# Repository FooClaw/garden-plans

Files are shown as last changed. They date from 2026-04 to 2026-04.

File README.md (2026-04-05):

# Garden Plans - Projets 3D pour le jardin

Modeles 3D parametriques (STL + plans techniques PDF) pour des meubles
de jardin a fabriquer soi-meme a partir de materiaux recycles.

## Projets

### Table basse en palettes recyclees

Repertoire : [`table_basse_palette/`](table_basse_palette/)

Table basse 100% bois de palette (1200 x 600 x 450 mm), inspiree du
projet [DIY Pallet Table](https://www.instructables.com/DIY-PALLET-TABLE-100-PALLET-WOOD/)
sur Instructables.

- Modele 3D (STL) + plan technique (PDF)
- Nomenclature detaillee avec guide de debit depuis 2 euro-palettes
- Guide de construction illustre pas a pas (12 pages)

### Chaise de jardin empilable en palettes recyclees

Repertoire : [`chaise_jardin_palette/`](chaise_jardin_palette/)

Chaise empilable adaptee a la table basse (assise 370 mm), inspiree du
projet [A Deck Chair Made From Pallet Wood Leftovers](https://www.instructables.com/A-Deck-Chair-Made-From-Pallet-Wood-Leftovers/)
sur Instructables.

- 1 palette = 1 chaise (20 pieces)
- Design empilable (pieds arriere retreci)
- Modele 3D (STL) + plan technique + guide 11 pages + nomenclature PDF

## Pre-requis

```bash
pip install numpy numpy-stl matplotlib
```

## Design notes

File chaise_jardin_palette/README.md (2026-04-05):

# Deck Chair de Jardin en Palettes Recyclees

Chaise de jardin type deck chair, 100% bois de palette.
Design minimaliste : assise tres basse, dossier tres incline, sans accoudoirs.
Panneaux lateraux style palette (planche + blocs + planche).

Fidellement inspire du projet [A Deck Chair Made From Pallet Wood Leftovers](https://www.instructables.com/A-Deck-Chair-Made-From-Pallet-Wood-Leftovers/)
par Well Done Tips sur Instructables. Adaptee pour accompagner la table basse palette (450 mm).

## Design

- Panneaux lateraux style palette : planche basse + 3 blocs + planche haute (122 mm)
- Assise tres basse (144 mm) - position transat, genoux au-dessus des hanches
- Dossier incline a ~125 degres - position tres detendue
- Pas d'accoudoirs - design epure et minimaliste
- Lattes pleine largeur (95 mm) avec ecarts de 15 mm
- Assise courte (4 lattes) couvrant toute la largeur (600 mm)
- Longerons depassant de 350 mm a l'arriere pour la stabilite
- Supports dossier continus du sol au sommet, inclines a 35 degres

## Dimensions

| Element | Dimensions |
|---|---|
| Chaise (L x P x H) | 600 x 775 x 677 mm |
| Hauteur assise | 144 mm |
| Angle dossier | ~125 degres |
| Panneaux lateraux | 775 x 95 x 122 mm |
| Assise | 4 lattes de 600 x 95 x 22 mm |
| Dossier | 5 lattes de 410 x 95 x 22 mm |
| Supports dossier | 826 x 70 x 44 mm |
| Blocs lateraux | 44 x 44 x 78 mm |
| Pieces totales | 22 (7 references) |

## Fichiers

| Fichier | Description |
|---|---|
| `generate_table.py` | Generateur STL + PDF technique |
| `generate_guide.py` | Generateur guide construction PDF |
| `generate_nomenclature.py` | Generateur nomenclature PDF |
| `chaise_jardin_palette.stl` | Maillage 3D |
| `chaise_jardin_palette_plan.pdf` | Plan technique |
| `guide_construction.pdf` | Guide illustre |
| `nomenclature.pdf` | Nomenclature PDF |
| `NOMENCLATURE.md` | Nomenclature source |

## Usage

```bash
pip install numpy numpy-stl matplotlib
python3 generate_table.py
python3 generate_guide.py
python3 generate_nomenclature.py
```

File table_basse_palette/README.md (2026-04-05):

# Table Basse en Palettes Recyclees

Modele 3D d'une table basse 100% bois de palette, inspire du projet
[DIY Pallet Table](https://www.instructables.com/DIY-PALLET-TABLE-100-PALLET-WOOD/)
sur Instructables.

## Design

- Plateau 6 lattes de palette alignees
- Etagere inferieure pour le rangement
- 4 pieds en blocs de palette
- Entretoises laterales pour la rigidite
- Materiau : euro-palette recyclee (lattes 22 mm)

## Dimensions

| Element | Dimensions |
|---|---|
| Table (L x l x H) | 1200 x 600 x 450 mm |
| Lattes plateau | 95 x 22 mm (x6) |
| Pieds | 95 x 95 x 406 mm |
| Etagere | a 100 mm du sol |
| Entretoises | 70 x 22 mm |

## Fichiers

| Fichier | Description |
|---|---|
| `generate_table.py` | Script Python (numpy-stl + matplotlib) |
| `table_basse_palette.stl` | Maillage 3D pour visualisation / impression |
| `table_basse_palette_plan.pdf` | Plan technique avec vues de face, dessus et cote |

## Usage

```bash
python3 generate_table.py
```

Genere le STL et le PDF. Necessite `numpy`, `numpy-stl` et `matplotlib`.

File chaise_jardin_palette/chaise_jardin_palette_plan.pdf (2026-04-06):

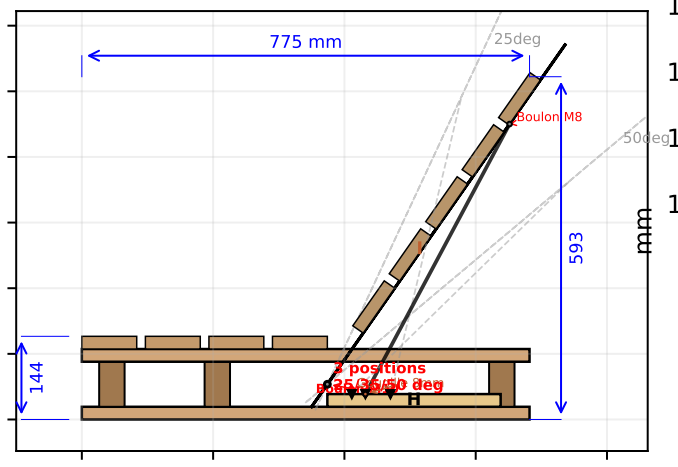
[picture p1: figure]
25deg; Boulon M8; 50deg; Boulon M10; Goupille 8mm; 3 positions 25/35/50 deg

0 | 50 | 100 | 150 | 200
| | mm

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
# Vue de cote

0 | 50 | 100 | 150 | 200
| | mm

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
600 mm

593

# Vue de face

0 | 20 | 40 | 60 | 80
| | mm

0

20

40

60

80

mm

600 mm

775 mm

# Vue de dessus

Objet : Deck Chair de Jardin en Palettes Recyclees
Dimensions : 600 x 775 x 593 mm (L x P x H) | | | Assise : 144 mm
Assise : 4 lattes | | | Dossier : 5 lattes, inclinable 3 positions (25/35/50 deg)
Mecanisme : 2 boulons M10 (pivot) + 2 boulons M8 (articulation) + goupille 8mm Panneaux lateraux style palette (planche + blocs 78 mm + planche)
Sans accoudoirs | | | Longerons depassent de 350 mm a l'arriere
Materiau : 1 euro-palette | | | 26 pieces | | | Echelle 1:1 (mm)
Inspire de : instructables.com/A-Deck-Chair-Made-From-Pallet-Wood-Leftovers

# Plan Technique - Deck Chair en Palettes Recyclees

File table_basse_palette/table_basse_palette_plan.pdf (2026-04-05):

0 200 400 600 800 1000 1200 mm

0

200

400

mm

1200 mm

450 mm

100

# Vue de face

0 200 400 600 800 1000 1200 mm

0

200

400

600

mm

1200 mm

600 mm

# Vue de dessus

0 100 200 300 400 500 600
mm

0

100

200

300

400

mm

600 mm

450 mm

# Vue de cote

Objet : Table Basse en Palettes Recyclees (100% bois de palette) Dimensions : 1200 x 600 x 450 mm (L x l x H)
Plateau : 6 lattes de 95 x 22 mm | | | Pieds : 95 x 95 x 406 mm
Etagere inferieure a 100 mm du sol | | | Entretoises : 70 x 22 mm
Materiau : Euro-palette recyclee (lattes 22 mm) | | | Echelle : 1:1 (mm)
Inspire de : instructables.com/DIY-PALLET-TABLE-100-PALLET-WOOD

# Plan Technique - Table Basse en Palettes Recyclees

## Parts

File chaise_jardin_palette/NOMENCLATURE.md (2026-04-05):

# Nomenclature - Deck Chair de Jardin en Palettes Recyclees

## Matiere premiere : Euro-palette

Il faut **1 euro-palette standard** (1200 x 800 mm) pour realiser 1 chaise.
Choisir une palette marquee **HT** (traitement thermique, sans produit chimique).
**Important** : conserver les blocs de palette (78 mm de haut) pour les panneaux lateraux.
22 pieces au total (7 references A-G).

---

## Recapitulatif de debit

| Ref | Piece | Qte | Dimensions (mm) | Origine palette |
|-----|---|-----|---|---|
| A | Latte assise | 4 | 600 x 95 x 22 | Lattes pleine largeur |
| B | Latte dossier | 5 | 410 x 95 x 22 | Lattes pleine largeur |
| C | Planche lat. basse | 2 | 775 x 95 x 22 | Lattes pleine largeur |
| D | Planche lat. haute | 2 | 775 x 95 x 22 | Lattes pleine largeur |
| E | Bloc lateral | 6 | 44 x 44 x 78 | Blocs de palette |
| F | Support dossier | 2 | 826 x 70 x 44 | 2 lattes collees |
| G | Traverse avant | 1 | 410 x 44 x 22 | Latte recoupee |
| | **Total pieces** | **22** | | **1 palette** |

---

## Structure des panneaux lateraux

Chaque panneau lateral est construit comme une mini-palette :

```
[=== Planche haute D (775 x 95 x 22) ===]
 [E]            [E]            [E]
[=== Planche basse C (775 x 95 x 22) ===]
```

Les blocs (E) sont espaces : avant, milieu et arriere du panneau.
Hauteur du panneau : 22 + 78 + 22 = **122 mm**.
Hauteur d'assise (avec latte) : 122 + 22 = **144 mm**.

---

## Instructions de debit

### Ref. A - Lattes d'assise (x4)
- **600 x 95 x 22 mm** - Lattes pleine largeur, recoupees a 600 mm
- Couvrent toute la largeur de la chaise, depassent des panneaux lateraux

### Ref. B - Lattes de dossier (x5)
- **410 x 95 x 22 mm** - Lattes pleine largeur, recoupees a 410 mm
- S'inserent entre les deux panneaux lateraux

### Ref. C/D - Planches laterales (2 + 2)
- **775 x 95 x 22 mm** - Lattes pleine largeur, recoupees a 775 mm
- Forment le bas (C) et le haut (D) des panneaux lateraux
- Depassent de 350 mm a l'arriere de l'assise

### Ref. E - Blocs lateraux (x6)
- **44 x 44 x 78 mm** - Blocs recuperes de la palette
- 3 par panneau (avant, milieu, arriere)
- Hauteur standard des blocs de palette euro

### Ref. F - Supports dossier (x2)
- **826 x 70 x 44 mm** - 2 lattes collees face a face
- Piece continue du sol au sommet du dossier, inclinee a ~35 deg de la verticale
- Boulonnee a travers le panneau lateral (2 boulons M8 par cote)
- La base repose au sol ~100 mm en avant de l'arriere de l'assise

### Ref. G - Traverse avant (x1)
- **410 x 44 x 22 mm** - Latte recoupee et refendue
- Relie les panneaux sous l'assise
- **410 x 44 x 22 mm** - Latte recoupee et refendue
- Relie les panneaux sous l'assise

---

## Outillage necessaire

| Outil | Usage |
|---|---|
| Pied-de-biche / levier | Demontage lattes et blocs |
| Arrache-clou / tenaille | Retrait des clous |
| Scie circulaire | Decoupe a longueur |
| Scie a onglet | Decoupe precision |
| Ponceuse orbitale | Poncage (grains 80, 120, 180) |
| Visseuse + vis 4x50 mm | Assemblage |
| Serre-joints (x4) | Collage supports dossier |
| Colle a bois D3 | Collage pieces doublees |
| Fausse equerre | Angle dossier (~125 deg) |

---

## Ordre d'assemblage

1. **Demontage** : Demonter la palette, conserver lattes ET blocs
2. **Debit** : Decouper toutes les pieces
3. **Poncage** : Poncer toutes les pieces
4. **Panneaux lateraux** : Planche basse + 3 blocs + planche haute (x2)
5. **Traverse** : Visser traverse avant G entre les panneaux
6. **Assise** : Visser 4 lattes A (espacement 15 mm)
7. **Supports dossier** : Boulonner supports F a travers les panneaux (angle ~35 deg)
8. **Dossier** : Visser 5 lattes B sur les supports
9. **Finition** : Huile de lin, vernis ou lasure

---

## Design

Fidellement inspire du projet Instructables
[A Deck Chair Made From Pallet Wood Leftovers](https://www.instructables.com/A-Deck-Chair-Made-From-Pallet-Wood-Leftovers/)
par Well Done Tips.

- Assise tres basse (144 mm) - position transat
- Dossier incline a ~125 deg
- Panneaux lateraux style palette (planche + blocs + planche)
- Lattes pleine largeur (95 mm) avec grands ecarts (15 mm)
- Longerons depassant de 350 mm a l'arriere
- Sans accoudoirs
- 1 palette suffit

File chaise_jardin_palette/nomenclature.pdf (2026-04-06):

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

# Quincaillerie (mecanisme)

Element | Qte | Usage
Boulon M10 x 120 + ecrou + 4 rondelles | 2 | Pivot dossier
Boulon M8 x 60 + ecrou papillon + 2 rondelles | 2 | Articulation barre stab.
Goupille fendue acier 8 mm x 50 mm | 2 | Verrouillage position
Vis a bois 4x50 mm | 50 | Assemblage general
Vis a bois 4x30 mm | 10 | Fixation rails

Tous les boulons sont en acier zingue (exterieur).

Les ecrous papillon permettent un reglage a la main.

# Ordre d'assemblage

Demontage

Demonter la palette, conserver lattes ET blocs

Debit

Decouper toutes les pieces aux bonnes dimensions

Poncage

Poncer toutes les pieces (grains 80, 120, 180)

Panneaux lat.

Planche basse + 3 blocs + planche haute (x2)

Traverses

Visser traverse avant G entre les panneaux

Assise

Visser 4 lattes A (espacement 15 mm)

Rails

Percer 3 trous de 10 mm dans H, fixer entre les planches

Supports

Coller F, monter sur pivot M10 au sommet du panneau

Barres stab.

Fixer barres I au support, pied sur rail + goupille

Dossier

Visser 5 lattes B sur supports

Verification

Tester les 3 positions, controler stabilite

Finition

Huile de lin, vernis ou lasure

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
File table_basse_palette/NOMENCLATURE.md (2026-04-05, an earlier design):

# Nomenclature - Table Basse en Palettes Recyclees

## Matiere premiere : Euro-palettes

Il faut **2 euro-palettes standard** (1200 x 800 mm) pour realiser cette table.
Choisir des palettes marquees **HT** (traitement thermique, sans produit chimique).
Eviter les palettes marquees **MB** (bromure de methyle, toxique).

```
Euro-palette standard (EPAL/EUR)
┌─────────────────────────────────────┐
│  1200 mm                            │
│ ┌──┐ ┌──┐ ┌──┐ ┌──┐ ┌──┐ ┌──┐ ┌──┐│
│ │  │ │  │ │  │ │  │ │  │ │  │ │  ││ 800 mm
│ └──┘ └──┘ └──┘ └──┘ └──┘ └──┘ └──┘│
│  7 lattes dessus (largeurs variables)│
│  9 blocs (plots)                     │
│  3 traverses + 3 lattes dessous      │
└─────────────────────────────────────┘
Epaisseur lattes : 22 mm
Largeur lattes : 95-145 mm (variable)
Hauteur totale : 144 mm
```

---

## Nomenclature des pieces

### Ref. A - Lattes du plateau (x6)

| Propriete | Valeur |
|---|---|
| Dimensions finies | 1200 x 95 x 22 mm |
| Origine sur palette | Lattes du dessus |
| Quantite necessaire | 6 |
| Palettes consommees | 2 (3 lattes par palette) |

**Debit :**
1. Retirer les lattes du dessus de la palette au pied-de-biche
2. Arracher les clous restants avec un arrache-clou ou une tenaille
3. Poncer les deux faces (grain 80, puis 120, puis 180)
4. Recouper a 1200 mm de long si necessaire
5. Selectionner les lattes de 95 mm de large (largeur standard)

> **Astuce :** Les lattes les plus larges (145 mm) peuvent etre refendues
> a la scie circulaire pour obtenir des lattes de 95 mm + des chutes
> utilisables pour les entretoises.

---

### Ref. B - Pieds (x4)

| Propriete | Valeur |
|---|---|
| Dimensions finies | 95 x 95 x 406 mm |
| Origine sur palette | Blocs (plots) empiles et colles |
| Quantite necessaire | 4 |
| Blocs par pied | 3 blocs empiles (3 x 144 mm ~ 432 mm, recoupe a 406 mm) |
| Blocs totaux | 12 (soit 2 palettes a 9 blocs = 18 disponibles) |

**Debit :**
1. Demonter la palette : retirer toutes les lattes dessus et dessous
2. Recuperer les 9 blocs (plots) par palette, ils restent solidaires des traverses
3. Scier les traverses au ras des blocs
4. Poncer les blocs (grain 80, puis 120)
5. Empiler 3 blocs et les coller a la colle a bois (serrer avec des serre-joints, 24h)
6. Une fois sec, recouper l'ensemble a 406 mm de hauteur a la scie a onglet
7. Poncer les faces de collage (grain 120)

> **Astuce :** Les blocs centraux de la palette font generalement
> 145 x 95 mm, et les blocs d'extremite 95 x 95 mm. Privilegier
> les blocs d'extremite pour des pieds carres reguliers.

---

### Ref. C - Lattes de l'etagere (x4)

| Propriete | Valeur |
|---|---|
| Dimensions finies | 1100 x 95 x 22 mm |
| Origine sur palette | Lattes du dessus ou du dessous |
| Quantite necessaire | 4 |
| Palettes consommees | Recuperation sur les memes palettes |

**Debit :**
1. Meme processus que les lattes du plateau (Ref. A)
2. Recouper a 1100 mm (= 1200 - 2 x 50 mm de retrait)
3. Poncer les deux faces

> **Note :** Les lattes du dessous de palette sont plus etroites
> (souvent 95 mm) et conviennent parfaitement pour l'etagere.

---

### Ref. D - Traverses du plateau (x3)

| Propriete | Valeur |
|---|---|
| Dimensions finies | 600 x 22 x 22 mm |
| Origine sur palette | Traverses ou lattes refendues |
| Quantite necessaire | 3 (2 laterales + 1 centrale) |
| Palettes consommees | Chutes des lattes |

**Debit :**
1. Recuperer les traverses de la palette (planches perpendiculaires aux lattes)
2. Les recouper a 600 mm de long (= largeur de la table)
3. Refendre en largeur a 22 mm si necessaire (epaisseur = largeur pour un profile carre)
4. Poncer (grain 120)

---

### Ref. E - Entretoises laterales (x2)

| Propriete | Valeur |
|---|---|
| Dimensions finies | 1010 x 22 x 70 mm |
| Longueur | 1200 - 2 x 95 = 1010 mm |
| Origine sur palette | Traverses ou lattes refendues a 70 mm |
| Quantite necessaire | 2 (avant + arriere) |

**Debit :**
1. Utiliser des traverses de palette ou des lattes larges
2. Refendre a 70 mm de largeur a la scie circulaire
3. Recouper a 1010 mm de long
4. Poncer (grain 120)

---

### Ref. F - Traverses de l'etagere (x2)

| Propriete | Valeur |
|---|---|
| Dimensions finies | 600 x 22 x 22 mm |
| Origine sur palette | Meme source que Ref. D |
| Quantite necessaire | 2 |

**Debit :** Identique a la Ref. D.

---

## Recapitulatif de debit

| Ref | Piece | Qte | Dimensions (mm) | Origine palette |
|-----|---|-----|---|---|
| A | Latte plateau | 6 | 1200 x 95 x 22 | Lattes dessus |
| B | Pied | 4 | 95 x 95 x 406 | 3 blocs colles |
| C | Latte etagere | 4 | 1100 x 95 x 22 | Lattes dessus/dessous |
| D | Traverse plateau | 3 | 600 x 22 x 22 | Traverses/chutes |
| E | Entretoise laterale | 2 | 1010 x 70 x 22 | Traverses/lattes |
| F | Traverse etagere | 2 | 600 x 22 x 22 | Traverses/chutes |
| | **Total pieces** | **21** | | **2 palettes** |

---

## Outillage necessaire

| Outil | Usage |
|---|---|
| Pied-de-biche / levier | Demontage des lattes |
| Arrache-clou / tenaille | Retrait des clous |
| Scie circulaire ou scie a onglet | Decoupe a longueur et refente |
| Ponceuse orbitale | Poncage (grains 80, 120, 180) |
| Serre-joints (x4 min.) | Collage des blocs pour les pieds |
| Visseuse + vis a bois (4x50 mm) | Assemblage |
| Colle a bois D3 (exterieur) | Collage des blocs pieds |
| Equerre de menuisier | Verification des angles droits |

---

## Ordre d'assemblage

1. **Demontage** : Demonter les 2 palettes, trier les pieces
2. **Debit** : Decouper toutes les pieces aux dimensions finales
3. **Poncage** : Poncer toutes les pieces avant assemblage
4. **Pieds** : Coller les blocs par 3, laisser secher 24h, recouper a 406 mm
5. **Cadre bas** : Visser les traverses etagere (F) entre les pieds
6. **Entretoises** : Visser les entretoises laterales (E) entre les pieds
7. **Etagere** : Poser et visser les lattes etagere (C) sur les traverses (F)
8. **Traverses plateau** : Visser les traverses (D) sur le haut des pieds
9. **Plateau** : Poser et visser les lattes (A) sur les traverses (D)
10. **Finition** : Huile de lin, vernis, ou lasure selon usage (interieur/exterieur)

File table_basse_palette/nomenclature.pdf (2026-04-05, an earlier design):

# Nomenclature

### Table Basse en Palettes Recyclees

# Liste de debit et instructions d'assemblage

Materiau : | 2 euro-palettes standard (1200 x 800 mm)
Dimensions table : | 1200 x 600 x 450 mm (L x l x H)
Nombre de pieces : | 21 pieces (6 references)
Outillage : | 9 outils necessaires
Etapes : | 10 etapes d'assemblage

Choisir des palettes marquees HT (traitement thermique)

Eviter les palettes marquees MB (bromure de methyle, toxique)

Euro-palette 1200 x 800 mm

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

# Instructions de debit (1/2)

Ref. A - Latte plateau | x6
Dimensions : 1200 x 95 x 22 mm | Origine : Lattes du dessus

Retirer les lattes du dessus au pied-de-biche

Arracher les clous restants a la tenaille

Poncer les deux faces (grain 80, puis 120, puis 180)

Recouper a 1200 mm de long si necessaire

Selectionner les lattes de 95 mm de large
Ref. B - Pied (3 blocs colles) | x4
Dimensions : 95 x 95 x 406 mm | Origine : Blocs empiles

Demonter la palette : retirer toutes les lattes

Recuperer les 9 blocs (plots) par palette

Scier les traverses au ras des blocs

Poncer les blocs (grain 80, puis 120)

Empiler 3 blocs, coller a la colle D3 (serre-joints, 24h)

Recouper l'ensemble a 406 mm a la scie a onglet
Ref. C - Latte etagere | x4
Dimensions : 1100 x 95 x 22 mm | Origine : Lattes dessus/dessous

Meme processus que les lattes du plateau (Ref. A)

Recouper a 1100 mm (= 1200 - 2 x 50 mm de retrait)

Les lattes du dessous conviennent parfaitement

# Instructions de debit (2/2)

Ref. D - Traverse plateau | x3
Dimensions : 600 x 22 x 22 mm | Origine : Traverses / chutes

Recuperer les traverses de la palette

Recouper a 600 mm de long (= largeur de la table)

Refendre en largeur a 22 mm si necessaire
Ref. E - Entretoise laterale | x2
Dimensions : 1010 x 70 x 22 mm | Origine : Traverses refendues

Utiliser des traverses ou des lattes larges

Refendre a 70 mm de largeur a la scie circulaire

Recouper a 1010 mm de long
Ref. F - Traverse etagere | x2
Dimensions : 600 x 22 x 22 mm | Origine : Traverses / chutes

Identique a la Ref. D

Recouper a 600 mm de long

# Outillage necessaire

Outil | Usage
Pied-de-biche / levier | Demontage des lattes
Arrache-clou / tenaille | Retrait des clous
Scie circulaire ou scie a onglet | Decoupe a longueur et refente
Ponceuse orbitale | Poncage (grains 80, 120, 180)
Visseuse + vis a bois (4x50 mm) | Assemblage
Serre-joints (x4 min.) | Collage des blocs pour les pieds
Colle a bois D3 (exterieur) | Collage des blocs pieds
Equerre de menuisier | Verification des angles droits
Metre ruban + crayon | Tracage et mesures

# Ordre d'assemblage

Demontage

Demonter les 2 palettes, trier les pieces

Debit

Decouper toutes les pieces aux dimensions finales

Poncage

Poncer toutes les pieces avant assemblage

Pieds

Coller les blocs par 3, laisser secher 24h, recouper a 406 mm

Cadre bas

Visser les traverses etagere (F) entre les pieds

Entretoises

Visser les entretoises laterales (E) entre les pieds

Etagere

Poser et visser les lattes etagere (C) sur les traverses (F)

Traverses plateau

Visser les traverses (D) sur le haut des pieds

Plateau

Poser et visser les lattes (A) sur les traverses (D)

Finition

Huile de lin, vernis, ou lasure selon usage

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
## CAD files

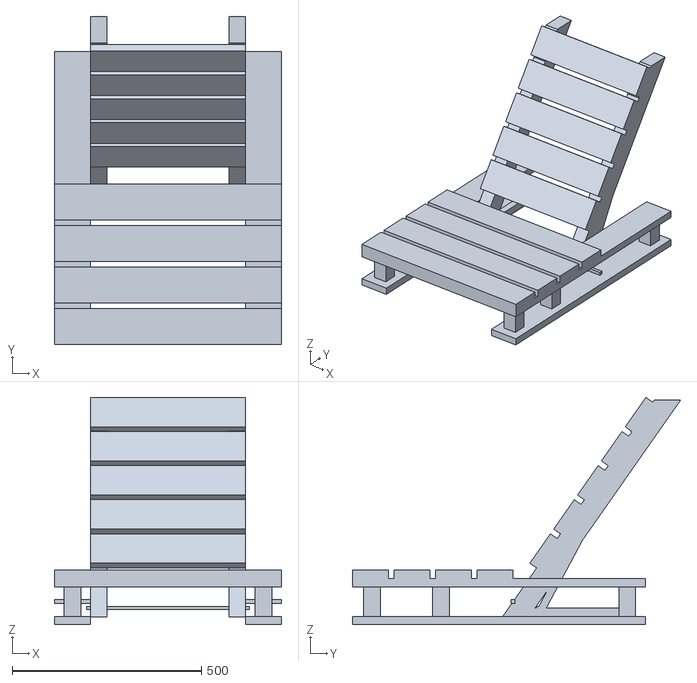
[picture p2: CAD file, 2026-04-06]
chaise_jardin_palette/chaise_jardin_palette.stl
600.0 x 867.8 x 600.5

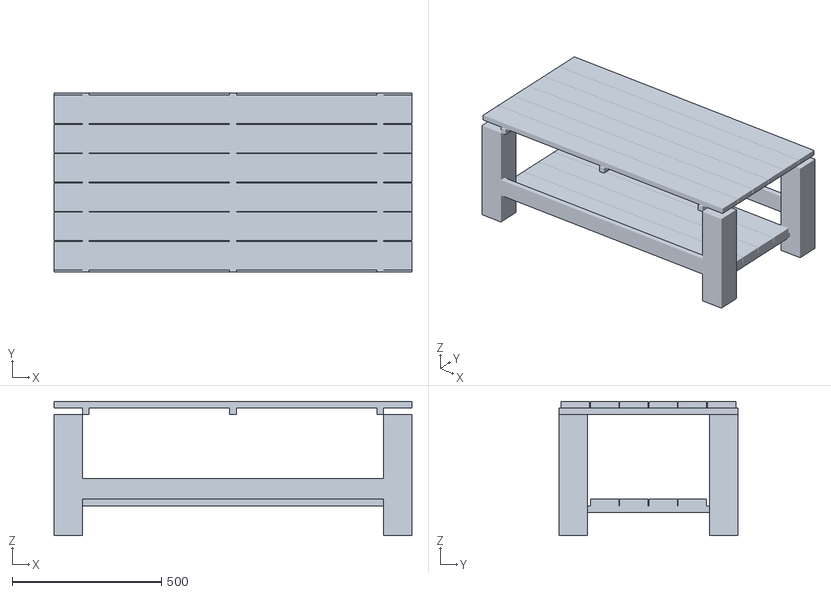
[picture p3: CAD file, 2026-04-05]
table_basse_palette/table_basse_palette.stl
1200.0 x 600.0 x 450.0

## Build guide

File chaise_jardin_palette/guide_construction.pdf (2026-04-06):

# Guide de Construction

## Deck Chair de Jardin en Palettes Recyclees

# Dossier inclinable 3 positions - mecanisme cremaillere

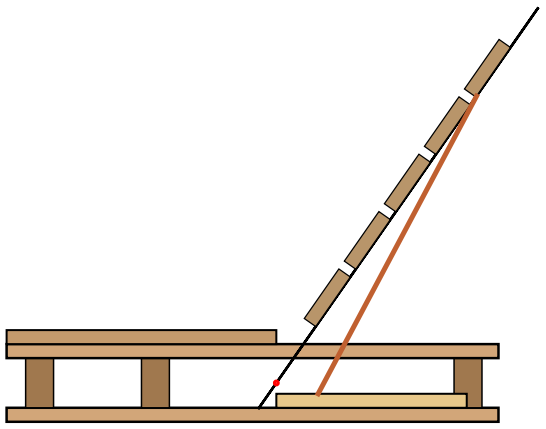
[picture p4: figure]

### 600 x 775 x 593 mm | Assise 144 mm | 3 positions (25/35/50 deg)

### Mecanisme cremaillere | Adaptee a la table basse palette

Inspire de : instructables.com/A-Deck-Chair-Made-From-Pallet-Wood-Leftovers

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

# Etape 1 : Demontage de la palette

### Levier

## Pieces a recuperer :

- Lattes du dessus (pleine largeur 95 mm)
- Blocs de palette (78 mm de haut) pour les panneaux lateraux
- Levier doucement pour ne pas casser les lattes
- Retirer tous les clous a la tenaille
- Conserver les blocs de palette (important !)
- Pas de refente : on garde la largeur 95 mm

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

# Etape 3 : Panneaux lateraux

### Assembler 2 panneaux : planche basse + 3 blocs + planche haute

C

E

D

### Structure identique a une mini-palette | Repeter x2

Vis 4x50 mm a travers les planches dans les blocs

Hauteur panneau : 122 mm | Longueur : 775 mm

# Etape 4 : Pose de l'assise

### Visser les 4 lattes (A) sur les panneaux lateraux

A

Vue de dessus - 4 lattes de 600 x 95 mm

### 15 mm

### Cale de 15 mm entre chaque latte | 2 vis par cote

### Hauteur d'assise : seulement 144 mm !

# Etape 4b : Preparation de l'angle

## Tracer et couper l'angle du dossier

verticale | F

### 35 deg

1. Regler la fausse equerre a 35 deg par rapport a la verticale

(= 125 deg par rapport a l'horizontale de l'assise)

2. Reporter l'angle sur les 2 supports dossier (F)

Longueur totale du support : 700 mm

3. Couper le pied du support en biseau a 35 deg

pour qu'il repose a plat au sol

4. Couper le sommet du support en biseau inverse

pour que le haut soit horizontal

5. Verifier les 2 supports ensemble :
- Meme longueur a +/- 2 mm
- Memes angles de coupe
- Poser cote a cote pour comparer

ASTUCE : tracer sur un panneau de MDF un gabarit grandeur nature

# Etape 5 : Supports dossier

### Monter les supports pivotants (F) + cremailleres (H)

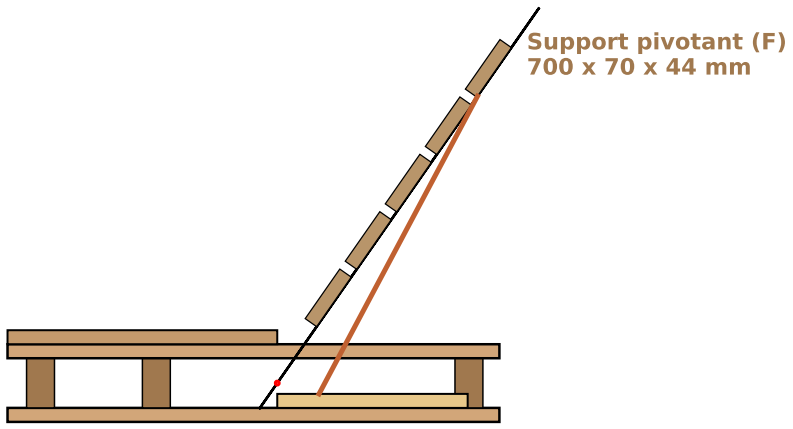
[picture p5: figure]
Support pivotant (F) 700 x 70 x 44 mm

Assemblage du support (F) :

1. Coller 2 lattes face a face (section 44 x 70 mm)

Serrer avec 4 serre-joints, laisser secher 24h

Montage du pivot (boulon M10 x 120) :

2. Percer un trou de 10 mm dans le support a 50 mm du bas
3. Percer les 2 planches du panneau (bord arriere, z=61 mm)
4. Inserer boulon M10 x 120 mm + 2 rondelles larges + ecrou

Le support doit pivoter librement (ne pas serrer a fond)

Rail crante (H) :

5. Fixer le rail (H) entre les planches du panneau

Pose sur la planche basse, du pivot vers l'arriere

6. Percer 3 trous de 10 mm aux positions calculees

pour les 3 positions (25/35/50 deg)

Repeter pour le 2e cote (symetrique).

# Etape 6 : Pose du dossier

### Visser les 5 lattes (B) sur les supports

B

Vue arriere - 5 lattes de 410 x 95 mm

### 2 vis par latte et par support = 20 vis

- Commencer par la latte du bas, 108 mm du pivot (le long du support)
- Espacement de 15 mm entre chaque latte (utiliser une cale)
- Pre-percer les lattes pour eviter de fendre le bois
- Vis 4x50 mm, 2 par cote, a ~20 mm des bords de la latte
- Verifier l'equerrage avec une equerre avant de serrer

# Etape 6b : Barres stabilisatrices (I)

## Relier le dossier aux rails crantes

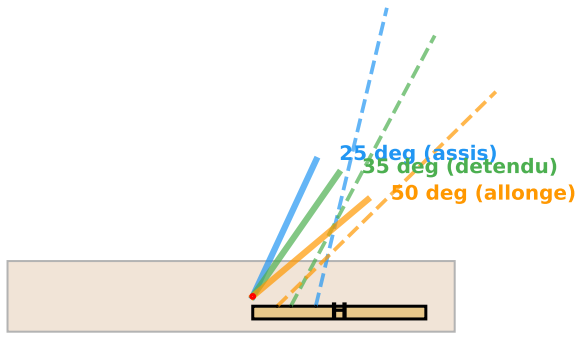
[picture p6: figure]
25 deg (assis) 35 deg (detendu); 50 deg (allonge)

1. Couper 2 barres (I) a 530 mm (section 22 x 22)

Percer un trou de 8 mm a chaque extremite

2. Fixer le HAUT au support (F) a 550 mm du pivot

Boulon M8 x 60 + rondelle + ecrou papillon

(la barre doit pouvoir pivoter librement)

3. Le PIED repose sur le rail (H), bloque par une

goupille fendue en acier de 8 mm de diametre

(la goupille traverse le trou du rail + la barre)

4. Pour changer de position :
- Retirer la goupille fendue
- Coulisser le pied sur le rail
- Aligner avec le trou souhaite (3 positions)
- Inserer la goupille et ouvrir les branches

# Etape 7 : Verification

## Controles avant finition

### Stabilite

[ ] Poser la chaise sur une surface plane

[ ] Verifier qu'elle ne bascule pas (4 points d'appui au sol)

[ ] S'asseoir doucement pour tester la solidite

### Mecanisme d'inclinaison

[ ] Tester les 3 positions (25/35/50 deg)

[ ] La barre doit tomber franchement dans chaque encoche

[ ] Le dossier ne doit pas glisser sous le poids

### Alignement des lattes

[ ] Les lattes d'assise doivent etre paralleles entre elles

[ ] Espacement regulier de 15 mm entre les lattes

[ ] Les lattes de dossier suivent l'inclinaison du support

### Fixations

[ ] Toutes les vis doivent etre serrees et affleurantes

[ ] Les boulons M8 des supports doivent etre bien bloques

[ ] Aucun jeu dans les assemblages

### Securite

[ ] Pas d'eclats ni d'aretes vives (poncer si necessaire)

[ ] Pas de clous ou vis qui depassent

[ ] Verifier la solidite des panneaux lateraux

## Si tout est OK, passer a la finition !

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

# Resultat Final

## Votre deck chair en palettes est terminee !

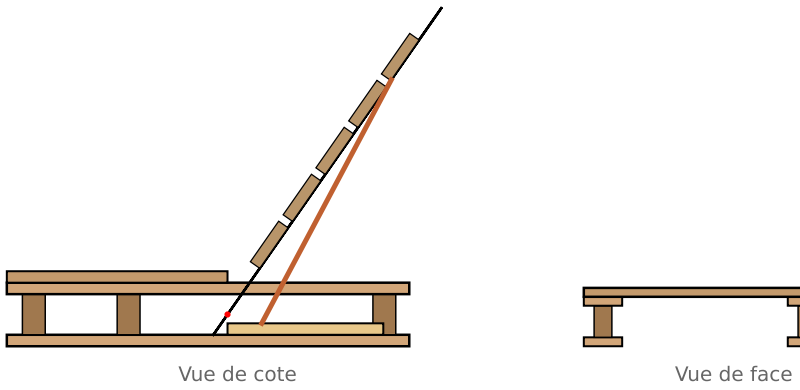
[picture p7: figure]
Vue de cote; Vue de face

Materiau : 1 euro-palette recyclee (marquage HT)

Dimensions : 600 x 775 x 593 mm

Hauteur assise : 144 mm seulement !

Dossier inclinable : 3 positions (25/35/50 deg)

Mecanisme cremaillere (barre + blocs crantes)

Panneaux lateraux style palette (blocs 78 mm)

Longerons depassent de 350 mm a l'arriere

25 pieces au total

Inspire de : instructables.com/A-Deck-Chair-Made-From-Pallet-Wood-Leftovers
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

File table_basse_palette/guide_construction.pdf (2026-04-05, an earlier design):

# Guide de Construction

### Table Basse en Palettes Recyclees

# 100% bois de palette recycle

### 1200 x 600 x 450 mm

6 lattes plateau | 4 pieds | etagere inferieure

Inspire de : instructables.com/DIY-PALLET-TABLE-100-PALLET-WOOD

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

# Etape 1 : Demontage des palettes

Vue laterale - insertion du pied-de-biche

latte

bloc

latte Levier

### Pieces recuperees :

Lattes (x14)

Blocs (x18)

Traverses (x6)

### Conseils :

- Inserer le levier entre la latte et le bloc
- Faire levier doucement pour ne pas casser les lattes
- Retirer tous les clous a la tenaille
- Trier les pieces par taille et etat

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

# Etape 3 : Poncage

### Poncer toutes les pieces avant assemblage

Grain 80

Degrossissage

Grain 120

Lissage

Grain 180

Finition

Sens du poncage (fil du bois)

1. Commencer par le grain 80 pour retirer les eclats et la salete
2. Passer au grain 120 pour lisser la surface
3. Finir au grain 180 pour une surface douce au toucher

Toujours poncer dans le sens du fil du bois

Depousssierer entre chaque grain

Insister sur les aretes pour les adoucir (chanfrein leger)

Porter un masque anti-poussiere

# Etape 4 : Fabrication des pieds

### Empiler et coller 3 blocs de palette par pied

Avant

Bloc 1

Bloc 2

Bloc 3

Colle D3

Collage

Serre-joints
24h de sechage

Resultat

406
mm

Recouper

## Repeter 4 fois (12 blocs au total)

Origine des blocs sur la palette :

9 blocs par palette = 18 blocs disponibles (12 necessaires)

# Etape 5 : Assemblage du cadre inferieur

### Visser les traverses et entretoises entre les pieds

Vue de face

F

E

Pied (B)

Vis 4x50 mm aux intersections (marques X)

### Ordre d'assemblage :

1. Poser 2 pieds a plat, ecartement = 1200 mm (ext. a ext.)
2. Visser la traverse F entre les pieds (a 100 mm du sol)
3. Visser l'entretoise E entre les pieds (au-dessus de F)
4. Repeter pour l'autre paire de pieds
5. Relier les 2 cadres avec les traverses F cote largeur

# Etape 6 : Pose de l'etagere

### Visser 4 lattes (C) sur les traverses inferieures

Vue de dessus de l'etagere

C4 - 1100 x 95 mm

C3 - 1100 x 95 mm

C2 - 1100 x 95 mm

C1 - 1100 x 95 mm

F

Vue de cote

Etagere (C)
100 mm

# Etape 7 : Traverses du plateau

### Fixer 3 traverses (D) sur le haut des pieds

Vue de dessus | (plateau retire)
D | D | D

B

1200 mm

Vue de face

D

Visser par le dessous a travers les traverses dans les pieds

# Etape 8 : Pose du plateau

### Poser et visser les 6 lattes (A) avec un espacement de 3 mm

Vue de dessus

A - 1200 x 95 mm

Detail de l'espacement :

### 3 mm

Latte

Latte

Utiliser une cale de 3 mm (ex: morceau de carton)

entre chaque latte pour un espacement regulier.

Visser chaque latte dans les 3 traverses (D) en dessous.

2 vis par intersection = 36 vis au total.

# Etape 9 : Finition

### Proteger et embellir votre table

- Aspect naturel et chaleureux
- Nourrit le bois en profondeur
- 2 a 3 couches, 24h entre couches
- Ideal pour usage interieur
- Protection maximale
- Surface lisse et brillante
- 2 couches + poncage fin entre couches
- Resistant aux taches et a l'eau
- Pour usage exterieur
- Protection UV et intemperies
- Teinte au choix (chene, noyer...)
- Renouveler tous les 2-3 ans

### Conseils generaux :

- Poncer legerement (grain 180) avant la premiere couche
- Depousssierer soigneusement au chiffon humide
- Appliquer dans le sens du fil du bois
- Laisser secher completement entre les couches
Huile de lin | Vernis polyurethane | Lasure bois

# Resultat Final

### Votre table basse en palettes recyclees est terminee !

Vue de face

1200 mm

450 mm

Vue de cote

600 mm

## Recapitulatif

Materiau : 2 euro-palettes recyclees (marquage HT)

Dimensions finales : 1200 x 600 x 450 mm (L x l x H)

Plateau : 6 lattes de 95 x 22 mm

Pieds : 4 x (95 x 95 x 406 mm)

Etagere : 4 lattes a 100 mm du sol

Nombre total de pieces : 21

Temps estime : 1 week-end (hors sechage colle)

Inspire de : instructables.com/DIY-PALLET-TABLE-100-PALLET-WOOD

Genere automatiquement avec Python (matplotlib + numpy-stl)
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

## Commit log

2026-04-04 Add first FreeCAD 3D object: parametric flower pot
    Parametric flower pot script with hollow walls, tapered shape,
    and drainage holes. Suitable for garden planning.
    https://claude.ai/code/session_014bopGVxemc3rBnRaCRgKTg
2026-04-05 Add static site for GitHub Pages and Netlify PR previews
    - index.html: landing page with project cards
    - table_basse_palette/index.html: project page with specs,
    downloads, BOM table, and construction steps
    - netlify.toml: config for Netlify deploy previews on PRs
    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
2026-04-05 Add GitHub Actions for Pages deploy and Netlify PR previews
    - deploy-pages.yml: builds STL/PDF outputs with Python, deploys
    to GitHub Pages on push to main
    - pr-preview.yml: builds and deploys PR previews to Netlify with
    comment on PR
    Both workflows generate the table basse files (STL + PDFs) as
    part of the build step before deploying.
    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
2026-04-05 Add pallet coffee table project with static site
    Complete DIY project for a recycled euro-pallet coffee table
    (1200x600x450mm) with:
    - Parametric 3D model generator (numpy-stl + matplotlib)
    - STL mesh for 3D printing / visualization
    - Technical drawing PDF with front, top and side views
    - 12-page illustrated step-by-step construction guide
    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
    [table_basse_palette.stl]
2026-04-05 Add nomenclature PDF generator, update CLAUDE.md conventions
    - generate_nomenclature.py: generates a 6-page PDF with BOM table,
    cutting instructions, tool list, and assembly order
    - Update CLAUDE.md: nomenclature PDF is now required for all projects
    - Update project index.html to link nomenclature PDF instead of markdown
    - Update CI workflows to build nomenclature PDF
    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
2026-04-05 Add stackable garden chair project (pallet wood)
    Complete DIY project for a stackable garden chair from recycled
    euro-pallet, designed to pair with the pallet coffee table (450mm).
    - Seat height 370mm, back legs narrower for stacking (4-5 chairs)
    - 20 pieces from 1 pallet, planks ripped to 70mm for lighter look
    - STL mesh, technical drawing PDF, 11-page illustrated guide,
    nomenclature PDF, project page, updated homepage
    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
    [chaise_jardin_palette.stl]
2026-04-05 Redesign chair as deck chair / Adirondack style closer to Instructables original
    Low seat (350mm), reclined backrest (~110°), wide armrests (95mm),
    long back legs (900mm) forming the backrest. 22 pieces from 1.5 palettes.
    Updated all generators, PDFs, STL, nomenclature, and HTML pages.
    [chaise_jardin_palette.stl]
2026-04-05 Redesign deck chair to match Instructables original closely
    Minimalist design faithful to Well Done Tips model:
    - No armrests (clean, simple look)
    - Very low seat (250mm vs 350mm before)
    - Full-width slats (95mm, not ripped to 70mm)
    - Angled back supports on floor runners (not vertical back legs)
    - Runners extend 200mm behind seat for stability
    - Only 17 pieces from 1 palette (vs 22 from 1.5 before)
    - Back tilted ~115 degrees for relaxed position
    [chaise_jardin_palette.stl]
2026-04-05 Adjust dimensions closer to Instructables photos
    - Lower seat: 180mm (was 250mm) - knees above hips like original
    - More reclined back: 30deg from vertical / 120deg (was 25/115)
    - Shorter seat: 4 slats (was 5) - legs extend past front
    - Taller back: 5 slats on 600mm supports (was 4 on 500mm)
    - Longer runner behind: 300mm (was 200mm) for stability
    - Wider gaps: 10mm between slats (was 6mm) matching visible gaps
    - Overall: 600 x 710 x 700mm, seat at 180mm
    [chaise_jardin_palette.stl]
2026-04-05 Redesign deck chair with pallet-style side panels to match Instructables original
    Replace thin frame rails with authentic pallet-style side panels (bottom plank +
    3 blocks + top plank = 122mm). Seat height now 144mm (very low, transat style),
    back tilted at 35deg from vertical (125deg). 22 pieces from 1 palette.
    Updated all generators, documentation, nomenclature, and HTML pages.
    [chaise_jardin_palette.stl]
2026-04-05 Add vertical anchor posts (H) to fix backrest structural support
    The backrest supports (F) were only attached at seat level with no ground
    anchorage, making the backrest unable to hold weight. Added vertical anchor
    posts (H, 144x70x44mm) bolted through the side panels from ground to seat
    height. The tilted back supports now rest on these solid anchors.
    24 pieces total (8 references A-H). Updated all generators, docs and HTML.
    [chaise_jardin_palette.stl]
2026-04-05 Fix backrest: use continuous support from ground to top (826mm)
    Replace anchor posts + separate tilted supports with a single continuous
    support piece per side (F, 826x70x44mm) running from ground level at
    y=324mm through the side panel up to the backrest top at 35deg tilt.
    The support is bolted through the side panel where it crosses, and its
    base rests on the ground - creating a rigid triangle that properly
    transfers backrest load to the ground. Back to 22 pieces, 7 references.
    [chaise_jardin_palette.stl]
2026-04-06 Fix backrest slat alignment to 35-deg tilt and improve construction guide
    - Add _backrest_slat_faces() for properly tilted STL slats perpendicular
    to the backrest surface instead of axis-aligned boxes
    - Fix side view PDF: draw backrest slats as rotated Polygons at 35 deg
    - Fix front view PDF: use projected slat height (SLAT_W * cos(35))
    - Use explicit slat spacing with margin along backrest axis
    - Add angle preparation page (step 4b) with detailed cutting instructions
    - Add verification checklist page (step 7) before finishing
    - Expand backrest support page with bolt positioning details
    - Add detailed tips to backrest slat page (pre-drilling, spacing cale)
    - Update nomenclature assembly or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
    [chaise_jardin_palette.stl]
2026-04-06 Move backrest supports inside the side panels
    Supports (F) are now positioned against the inner face of each side
    panel instead of centered on them. This is more realistic structurally
    and matches typical pallet furniture construction.
    - STL: supports at x=PANEL_W and x=CHAIR_WIDTH-PANEL_W-FRAME_W
    - PDF front view: updated support positions with dashed lines
    - Guide: updated backrest rear view + support fixing instructions
    https://claude.ai/code/session_01S28GkSaU7B9a9P6BEcLUWJ
    [chaise_jardin_palette.stl]
2026-04-06 Regenerate nomenclature PDF with updated assembly order
    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
2026-04-06 Add beach-chair style reclining mechanism (crémaillère)
    Backrest now pivots at the top of the side panel with 3 lockable
    positions (25°/35°/50°) using a cross-bar and notched blocks:
    - Pivot bolt (M10) at back of seat, top of panel
    - Support (F) shortened to pivot length (700mm), starts below pivot
    - Crémaillère (H x2): notched blocks on outside of each panel
    - Cross-bar (I x1): spans full width + overshoot into notches
    - 3 positions: 25° (sitting), 35° (relaxed), 50° (reclined)
    STL shows default 35° position with all mechanism parts.
    PDF side view shows all 3 ghost positions in dashed lines.
    Guide adds step 6b (mechanism page) with colored position diagram.
    Nomenclature updated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
    [chaise_jardin_palette.stl]
2026-04-06 Redesign mechanism: internal crémaillère + diagonal strut bars
    Replace external crémaillère blocks with internal mechanism:
    - Crémaillère (H x2) now INSIDE the panels, on the runner behind
    the pivot — no more external protrusions
    - Strut bars (I x2) connect diagonally from high on the backrest
    support (400mm from pivot) down to the crémaillère notches
    - Strut length 380mm, pivots at both ends (M8 bolts)
    - 3 notch positions for 25°/35°/50° backrest angles
    - Notch spread ~28mm along the crémaillère
    Side view PDF shows all 3 strut positions with ghost lines.
    Front view shows internal crémaillères between the panels.
    Total pieces: 26 (H x2 + I x2 instead of H x2 + I x1).
    h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
    [chaise_jardin_palette.stl]
2026-04-06 Move pivot between side panel planks (61mm height)
    The rotation mechanism now sits between the two planks of the side
    panel, in the block zone (z=61mm instead of z=122mm at panel top).
    This is structurally stronger as the bolt passes through both planks.
    - PIVOT_Z = SLAT_T + BLOCK_H/2 = 61mm (was PANEL_H = 122mm)
    - Crémaillère (H) sits on the bottom plank (z=22 to 62mm)
    - Backrest slats repositioned to start above seat level only
    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
    [chaise_jardin_palette.stl]
2026-04-06 Replace crémaillère blocks with horizontal notched rail
    The vertical notched blocks (crémaillère) are replaced by horizontal
    rails (H) running from the pivot to the back of the chair, between
    the side panel planks. The strut foot slides along the rail and is
    locked in position with a pin through one of 3 holes.
    - Rail (H x2): horizontal bar on the bottom plank (z=22-44mm)
    running from SEAT_DEPTH to ~170mm behind, with 3 holes
    - Strut foot rests on top of the rail (z=44mm)
    - Pin through strut + rail hole locks the angle
    - To adjust: pull pin, slide strut, reinsert pin
    - Notch positions spread ~62mm apart (good separation)
    Simpler mechanism, easier to build, no V-notch cutting needed.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
    [chaise_jardin_palette.stl]
2026-04-06 Realistic mechanism: high strut attachment, long rail, real hardware
    Major improvements for a buildable, credible design:
    Geometry:
    - Strut attaches near top of backrest (550mm from pivot, was 400mm)
    - Strut length 530mm (was 380mm) for proper reach
    - Rail extended to 300mm (full runner, from pivot to back)
    - 3 pin positions spread over ~67mm (good separation)
    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
    [chaise_jardin_palette.stl]
